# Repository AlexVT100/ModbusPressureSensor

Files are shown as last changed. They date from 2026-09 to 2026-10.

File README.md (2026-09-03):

<H1>
<picture>
    <source media="(prefers-color-scheme: dark)" srcset="images/icon_dark.svg" width="80" />
    <source media="(prefers-color-scheme: light)" srcset="images/icon.svg" width="80" />
    
</picture>
The Modbus Pressure Sensor
</H1>

## The Project's goal

The project is designed to continuously monitor coolant pressure in a residential home's heating system using Home Assistant.

## The Project's Prototype

This project is based on [Датчик давления воды для умного дома](https://www.drive2.ru/c/718805452854398890/)

## Features

* **Continuous pressure monitoring:** Tracks coolant pressure and publishes it via an integrated Modbus server.
* **Status register:** Indicates sensor failure or user-defined pressure threshold violations.
* **Integrated Telnet server:** Allows for easy remote monitoring, debugging, and configuration.
* **Custom integration for Home Assistant:** Configurable Python-based sensor integration and YAML-based alerting automation.

## Schematic

### Breadboard View

<br />Sensor Breadbord View

### Schematic Diagram

<br />
<picture>
    <source media="(prefers-color-scheme: dark)" srcset="images/schematic_dark.svg" width="600" />
    <source media="(prefers-color-scheme: light)" srcset="images/schematic_light.svg" width="600" />
    Sensor Schematic
</picture>

The [Fritzing project file](hardware/schematics/fritzing/Sensor.fzz) can be found in `schematic` folder.

## Assembly

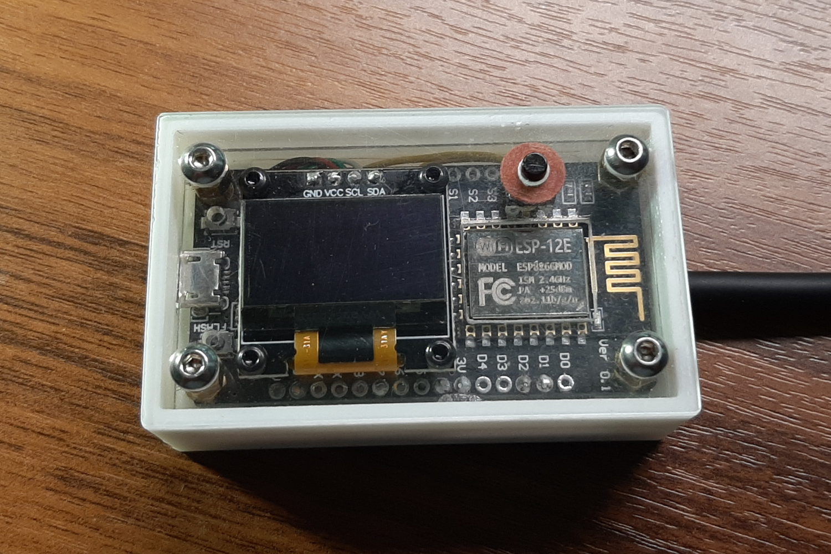
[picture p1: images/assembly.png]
The finlal assembly
<br />

<details>
  <summary>More pictures</summary>
  
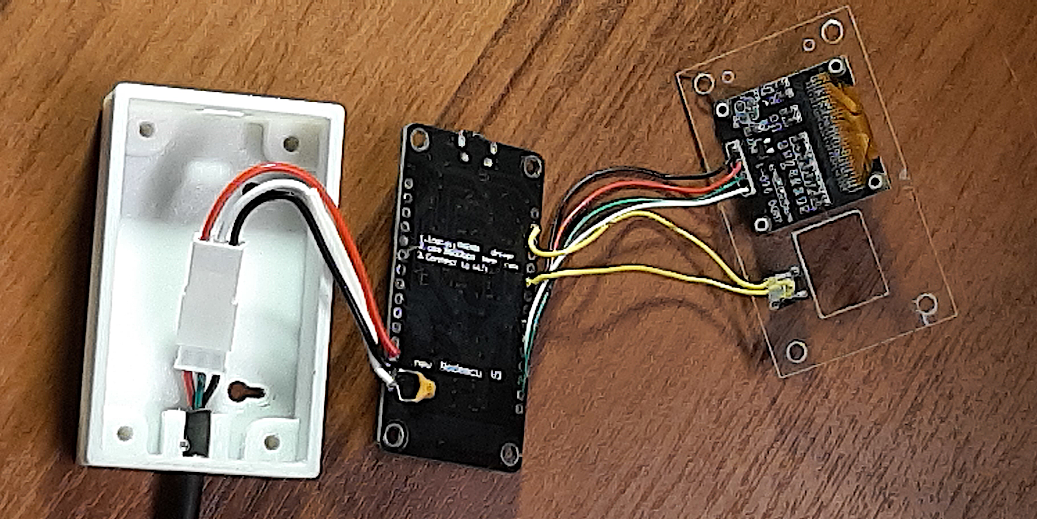
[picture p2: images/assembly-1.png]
  <br />
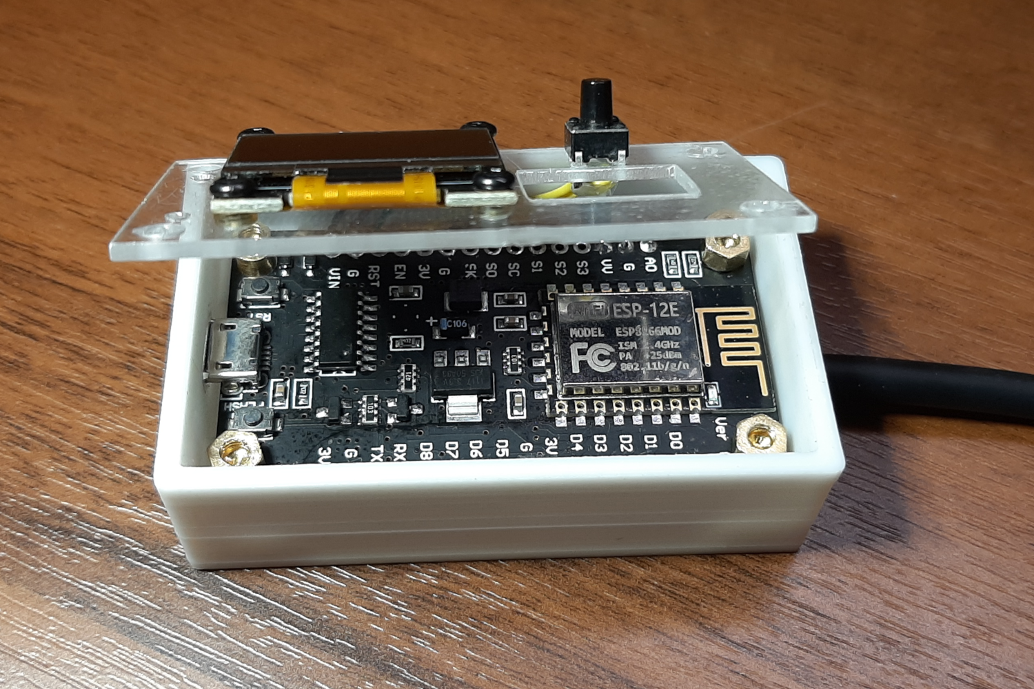
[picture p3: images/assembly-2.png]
  <br />
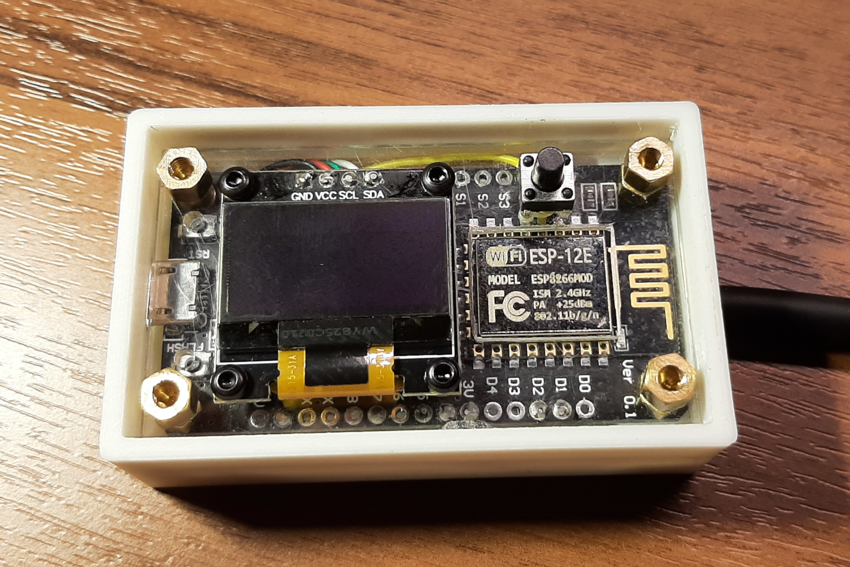
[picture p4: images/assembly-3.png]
  <br />

</details>

## Firmware

The sensor's firmware is developed in C++ using the [VSCode PlatformIO add-on](https://platformio.org/).

### Telnet output example:

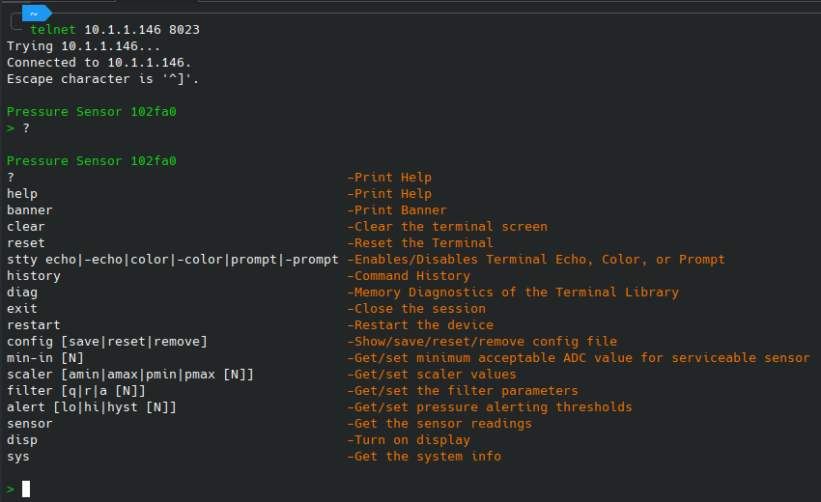
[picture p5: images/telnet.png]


### Used Arduino Libraries

* [Adafruit_SSD1306](https://github.com/adafruit/Adafruit_SSD1306) by Adafruit
* [ArduinoJson](https://github.com/bblanchon/ArduinoJson) by Benoit Blanchon
* [modbus-esp8266](https://github.com/emelianov/modbus-esp8266) by Andre Sarmento Barbosa and Alexander Emelianov
* [Terminal](https://github.com/johngavel/Terminal) by John J. Gavel
* [WiFiManager](https://github.com/tzapu/WiFiManager) by tzapu

## Home Assistant Integration

### Modbus Sensor Integration

The integration provides the Modbus Pressure Sensor device and entities to Home Assistant.

#### Installation

1. **Copy the component folder:** Copy the  `hass/custom_components/modbus_pressure_sensor` directory into your
`<hass volume>/custom_components/` directory.
2. **Restart Home Assistant:** Navigate to `Settings` ➞ `System` ➞ `⁝` (top right) ➞ `Restart Home Assistant` ➞ `Restart`.
3. **Configure the device:** Once Home Assistant restarts, navigate to `Settings` ➞ `Devices & Services` ➞ `Add Intergration` 
➞ search for `Modbus Pressure Sensor` and input your `Host`, `Port`, and `Device ID` in the configuration window.
4. **Verify connection:** Check the newly created sensor entities to confirm successful data transmission.

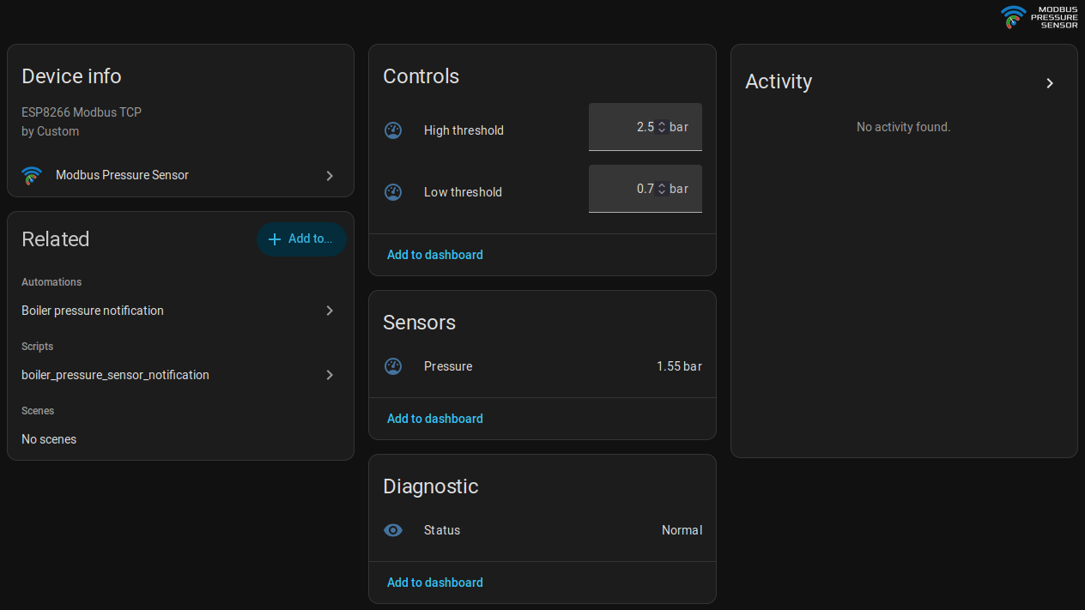
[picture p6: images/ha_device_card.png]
Sensor Breadbord View
<br />

### Alerting Automation (Optional)

This automation triggers notifications for the following events based on the status register:

* **Low pressure:** The pressure drops below the minimum threshold.
* **High pressure:** The pressure exceeds the maximum threshold.
* **Sensor failure:** The sensor reports an internal hardware error.
* **Sensor unavailable:** The sensor loses connection or stops reporting data.
* **Normal operation**: The pressure returns to the safe, standard range.

#### Installation

1. **Copy the configuration file:** Copy the `hass/packages/boiler_pressure_sensor.yaml` file into your `<hass volume>/packages/` directory.
2. **Reload configuration:** Navigate to `Settings` ➞ `⁝` (top right) ➞ `Restart Home Assistant` ➞ `Quick reload`.

## Other Useful Info

* [How to Fix Noisy Sensor Readings: Filtering Techniques for Arduino](https://zbotic.in/how-to-fix-noisy-sensor-readings-filtering-techniques-for-arduino/)

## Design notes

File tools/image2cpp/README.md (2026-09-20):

# Image to CPP Converter

Created by ChatGPT from the sources of https://github.com/javl/image2cpp

Below is a complete Python CLI tool that closely replicates the behavior of image2cpp.
It supports the same important options used in CLI ports of the project: format selection, draw mode, threshold, inversion, and bit swapping. The original tool converts images into byte arrays for microcontroller displays such as Arduino OLEDs.

This version aims to match the typical command-line usage found in community CLI conversions.

## Install dependencies

```shell
pip install pillow
```

## Example usage (same style as image2cpp CLI)

### Convert image → Arduino bitmap

```shell
python image2cpp_cli.py \
 -i logo.png \
 -o logo.c \
 -f arduino \
 -m horizontal1bit \
 -n logoBitmap
```

### Invert image

```shell
python image2cpp_cli.py -i icon.png -x
```

### Vertical byte layout

```shell
python image2cpp_cli.py -i icon.png -m vertical1bit
```

### Swap bits (useful for U8g2)

```shell
python image2cpp_cli.py -i icon.png -s
```

### Output example

```cpp
// 'logo', 128x64px
const unsigned char logo[] PROGMEM = {
  0x00, 0xFF, 0x81, 0x81, ...
};
```

## Features implemented

- CLI arguments compatible with typical image2cpp usage
- Horizontal / vertical 1-bit modes
- Arduino / plain / Adafruit GFX output
- Bit swapping
- Inversion
- Threshold control

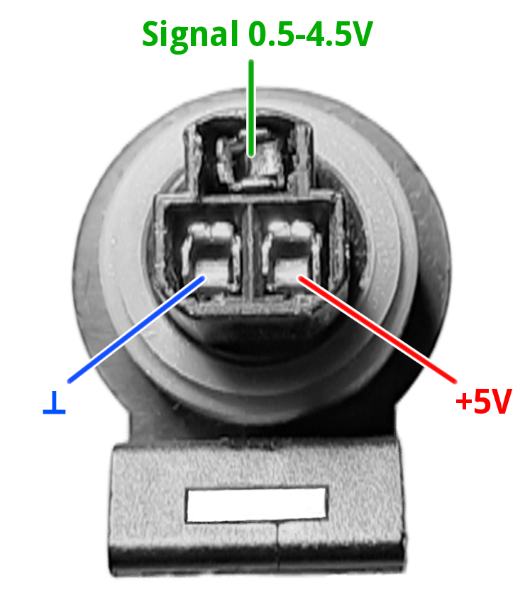
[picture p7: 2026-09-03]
images/sensor_connector.png

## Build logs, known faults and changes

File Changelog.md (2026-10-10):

# Changelog

## Firmware

### 1.2.0 (2026-10-10)
* WiFi connection logic improvement:
  * Previously, if the configured WiFi network was unavailable when the sensor started up,
    the WiFi subsystem was switched to AP mode and deleted the saved Wi-Fi credentials.
    Now, if the sensor already has saved WiFi credentials, it waits up to 5 minutes to
    connect and then restarts. It switches to AP mode only when the button is pressed
    or when no credentials are saved.
* Code reorganization:
  * The filters and the scaler have been moved to the separate files in lib/.
* Kalman filter improvements:
  * Renamed several methods.
  * Added checks for the covariance values.
  * Extended some variables to `uint64_t` to prevent potential overflow.
  * Changed `X` and `P` to use rounding instead of flooring.
* Added a unit test for Kalman filter.
* Telnet server optimization:
  * Joined commands `scale_in` and `scale_out` into single `scaler` with four parameters.
  * Removed custom GIT_REVISION and BUILD_TIME macros as they cause full rebuild on each build.
  
### 1.1.1 (2026-09-09)
* Optimized the telnet server:
	* Simplfied output of some telnet commands.
	* Removed duplicated output from the `config` command.
	* Optimized some command functions.

### 1.1.0 (2026-09-08)
* Reworked filtering:
  * The simple average filter replaced with the median filter.
  * Added the Kalman filter.
  * Added two additional Modbus input registers for debugging - the ADC readings after the median
    filter (raw) and after the Kalman filter (to be scaled).
  * The filters moved from functions.h to Filters.h/Filters.cpp.
  * scale() moved from functions.h to main.cpp.
  * Removed functions.h.
  * Removed the test scaler command from the Telnet server.

### 1.0.0 (2026-09-02)
* The first release

## Home Assistant Integration

### 1.0.0 (2026-09-02)
* The first release

## Home Assistant Automation

### 1.0.0 (2026-09-02)
* The first release

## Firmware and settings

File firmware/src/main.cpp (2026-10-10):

#include <Adafruit_SSD1306.h> // OLED display
#include <SoftwareSerial.h>   // Software UART
#include <Wire.h>

#include "ModbusHelper.h"
#include "WiFiHelper.h"

#include "Config.h"
#include "DebouncedButton.h"
#include "TelnetServer.h"
#include "TerminalLogger.h"

#include "scaler/scaler.h"
#include "filters/ema.h"
#include "filters/kalman.h"
#include "filters/median.h"

#include "States.h"
#include "bitmaps.h"

//=============================================================================
// General Settings
//=============================================================================

// SSD1306 display settings
// Character dimensions (WxH):
//      Text size 1: 5x7 (vertical spacing 1)
//      Text size 3: 15x21 (vertical spacing 2)
#define SCREEN_WIDTH   128
#define SCREEN_HEIGHT  64
#define OLED_RESET     -1 // Sharing Arduino reset pin
#define SCREEN_ADDRESS 0x3C

// Board-dependent values (discover_board.py)
#if defined(BOARD_1A86_7523) // Development board HW364A with a display and USB-C
#    define OLED_SDA     14  // D6
#    define OLED_SCL     12  // D5
#    define SERIAL_SPEED 115200
#elif defined(BOARD_0403_6001)  // No name board with MicroUSB used in the sensor assembly
#    define OLED_SDA     4      // D2
#    define OLED_SCL     5      // D1
#    define SERIAL_SPEED 115200 // 74880
#else                           // Defaults
#    define OLED_SDA     4      // D2
#    define OLED_SCL     5      // D1
#    define SERIAL_SPEED 115200
#    warning No board is connected. The image may not work as expected.
#endif

// The button pin. D5, D6 and D7 are available
#define BUTTON_PIN D7

// The size of an ADC samples buffer for oversampling
constexpr size_t MEDIAN_SIZE = 9;

//=============================================================================
// Global variables and containers
//=============================================================================

// WiFi
static constexpr unsigned WiFiConnTimeout = 300; // WiFi connection timeout, s

// Timers
static constexpr ulong SensorInterval = 500;    // Sensor polling interval, ms
static constexpr ulong DisplayInterval = 60000; // Display off timeout, ms

// millis() rollover counter for full uptime counting
ulong RolloverCount = 0;

// Display state
DisplayState DispState;

// The sensor values
SensorState Sensor;

//=============================================================================
// Global objects
//=============================================================================

// SSD-1306 display object
Adafruit_SSD1306 Display(SCREEN_WIDTH, SCREEN_HEIGHT, &Wire, OLED_RESET);

// Button press detector with debouncing
DebouncedButton Button(BUTTON_PIN);

// Wi-Fi object
WiFiHelperClass WiFiHelper("Press_Sensor_AP", Display);

// Config object
// Default settings are hardcoded in FileConfig::_setDefaults in Config.h
FileConfig Conf;

// Modbus object
ModbusHelperClass ModbusHelper;

// Kalman filter
KalmanFilterClass KalmanFilter;

// Telnet terminal and Logger
TelnetServer   Telnet(8023);
TerminalLogger Logger(Telnet);

//=============================================================================
// Forward declarations for the local functions
//=============================================================================

void      blinkLEDForever();
void      readSensor();
uint32_t *readSamples(uint8_t pin);
void      updateDisplay();
void      drawThrobber(int x, int y, int w, int h);

inline void setLEDOn() { digitalWrite(LED_BUILTIN, LOW); }
inline void setLEDOff() { digitalWrite(LED_BUILTIN, HIGH); }

// #############################################################################
//  Initialization
// #############################################################################
//
void setup() {
    Serial.begin(SERIAL_SPEED);
    while (!Serial && millis() < 3000);
    Serial.flush();

    Serial.println("\nInitialization...");

    // Switch on the built-in LED
    pinMode(LED_BUILTIN, OUTPUT);
    setLEDOn();

    // Arm the button
    pinMode(BUTTON_PIN, INPUT_PULLUP);
    Button.begin();

    // Init the display
    Wire.begin(OLED_SDA, OLED_SCL);
    if (!Display.begin(SSD1306_SWITCHCAPVCC, SCREEN_ADDRESS)) {
        // Fatal error
        blinkLEDForever();
    }
    Display.clearDisplay();
    Display.setTextSize(1);
    Display.setTextColor(SSD1306_WHITE);

    // Init the WIFI
    if (digitalRead(BUTTON_PIN) == LOW || WiFi.SSID().length() == 0) {
        // The button is pressed or no saved credentials -- enter WiFi configuration mode
        Display.clearDisplay();
        Display.setCursor(0, 0);
        Display.println(WiFi.SSID().length() == 0 ? "No WiFi credentials" : "Button pressed");
        Display.println("Starting WiFi Manager");
        Display.display();
        delay(2000);
        WiFiHelper.startWiFiManager();
    } else {
        WiFiHelper.connectToSavedWiFi(WiFiConnTimeout);
    }

    // Initialize the telnet server and te logger
    Telnet.setup();
    Logger.setup();

    // Load the configuration
    Conf.load();

    // Start the Modbus server and configure the registers
    ModbusHelper.setup();

    // Init the Kalman filter
    KalmanFilter.setCovs(Conf.kalmanQ(), Conf.kalmanR());

    // Switch off the LED
    setLEDOff();

    Serial.println("Ready");
}

// #############################################################################
//  The main loop
// #############################################################################
//
void loop() {
    static unsigned long lastMillis = millis();
    static unsigned long sensorTimer = lastMillis;
    static unsigned long displayTimer = lastMillis;

    unsigned long curMillis = millis();

    // Check if millis() rolled over back to 0
    if (curMillis < lastMillis) RolloverCount++;
    lastMillis = curMillis;

    if (curMillis - sensorTimer >= SensorInterval) {
        sensorTimer = curMillis; // Set the timer

        // Read the sensor and update the display and the Modbus registry
        readSensor();
        updateDisplay();
        ModbusHelper.pressure(Sensor.pressure >= 0 ? Sensor.pressure : 0);
        ModbusHelper.status(Sensor.status);
        ModbusHelper.adcRaw(Sensor.adcValueRaw);
        ModbusHelper.adc(Sensor.adcValue);
    }

    if (Button.wasPressed() || DispState.setOn) {
        // Switch on the display
        displayTimer = curMillis; // Set the timer
        Display.dim(false);
        DispState.isOn = true;
        DispState.setOn = false;
    }

    if (DispState.isOn && curMillis - displayTimer >= DisplayInterval) {
        // Switch off the display
        Display.dim(true);
        DispState.isOn = false;
    }

    Telnet.loop();
    ModbusHelper.loop();
    Conf.save();

    // Re-init the Kalman fiter if Q and/or R have changed
    if (KalmanFilter.covsChanged()) {
        if (KalmanFilter.setCovs(Conf.kalmanQ(), Conf.kalmanR()))
            Logger.println(INFO, F("Kalman covariance values are updated"));
        else
            Logger.println(ERROR, F("One or more Kalman filter covariance values are negative"));
    }
}

//-----------------------------------------------------------------------------
// Read the sensor
//-----------------------------------------------------------------------------
//
void readSensor() {
    //
    // Read and filter the ADC value
    //
    Sensor.adcValueRaw = median_filter(readSamples(A0), MEDIAN_SIZE);
    Sensor.adcValue    = KalmanFilter.update(Sensor.adcValueRaw);

    //
    // Calculate the pressure (mbar)
    //
    if (Sensor.adcValue > Conf.adcMinServ()) {
        Sensor.pressRaw =
            scale(Sensor.adcValue, Conf.scalerAmin(), Conf.scalerAmax(), Conf.scalerPmin(), Conf.scalerPmax());
        if (Sensor.pressRaw < 0) {
            Sensor.pressure = 0;
        } else {
            // Pressure is rounded to tens
            Sensor.pressure = ema_filter(Sensor.pressRaw, Conf.emaAlpha() * 100);
            Sensor.pressure = ((Sensor.pressure + 5) / 10) * 10;
        }

        // Set the sensor status
        if (Sensor.status == Status::LO_PRESS) {
            if (Sensor.pressure > Conf.alertLo() + Conf.alertHyst()) Sensor.status = Status::NORMAL;
        } else if (Sensor.status == Status::HI_PRESS) {
            if (Sensor.pressure + Conf.alertHyst() < Conf.alertHi()) Sensor.status = Status::NORMAL;
        } else {
            if (Sensor.pressure < Conf.alertLo())
                Sensor.status = Status::LO_PRESS;
            else if (Sensor.pressure > Conf.alertHi())
                Sensor.status = Status::HI_PRESS;
            else
                Sensor.status = Status::NORMAL;
        }
    } else {
        Sensor.pressure = 0;
        Sensor.status   = Status::FAILURE;
    }
}

//-----------------------------------------------------------------------------
// Read MEDIAN_SIZE of samples into the static buffer
//-----------------------------------------------------------------------------
//
uint32_t *readSamples(uint8_t pin) {
    static uint32_t buf[MEDIAN_SIZE];

    // Ignore the first reading in a series as it usually stands out
    // of the rest (an ADC peculiarity? an RC-filter feature?)
    analogRead(pin);

    // Collect the samples
    for (size_t i = 0; i < MEDIAN_SIZE; i++) {
        delay(2);
        buf[i] = analogRead(pin);
    }

    return buf;
}

//-----------------------------------------------------------------------------
// Update the display
//-----------------------------------------------------------------------------
//
void updateDisplay() {

    if (!DispState.isOn) return;

    Display.clearDisplay();
    Display.setCursor(0, 0);
    Display.setTextColor(SSD1306_WHITE);

    // Display.drawRect(0, 0, 128, 64, SSD1306_WHITE);

    // Print the WiFi info
    Display.setTextSize(1);
    Display.print("WiFi: ");
    Display.println(WiFiHelper.SSID());
    Display.print("  IP: ");
    Display.println(WiFiHelper.localIP());

    Display.println("");

    // Draw the icon depending on the Sensor.pressure value
    const unsigned char *bitmap;
    switch (Sensor.status) {
        case Status::NORMAL: // The Sensor.pressure is normal
            setLEDOff();
            bitmap = bitmap_none;
            break;
        case Status::LO_PRESS: // The Sensor.pressure is too low
            setLEDOn();
            bitmap = bitmap_low;
            break;
        case Status::HI_PRESS: // The Sensor.pressure is too high
            setLEDOn();
            bitmap = bitmap_high;
            break;
        default: // Just in case
            Sensor.status = Status::FAILURE;
        case Status::FAILURE: // The sensor failure
            setLEDOn();
            bitmap = bitmap_fault;
            break;
    }
    Display.drawBitmap(Display.getCursorX(), Display.getCursorY(), bitmap, BITMAP_W, BITMAP_H, SSD1306_WHITE);

    // Display the Sensor.pressure
    if (Sensor.status != Status::FAILURE) {
        Display.setTextSize(3);
        Display.setCursor(BITMAP_W + 8, Display.getCursorY());
        Display.printf("%u.%02u", Sensor.pressure / 1000, Sensor.pressure % 1000 / 10);
        // Display.setCursor(Display.getCursorX(), 38);  // Uncomment to align the next line on the bottom
        Display.setTextSize(1);
        Display.print(" bar");
    } else {
        Display.setTextSize(2);
        Display.setCursor(BITMAP_W + 8, Display.getCursorY() - 4);
        Display.println("Sensor");
        Display.setCursor(BITMAP_W + 8, Display.getCursorY() - 2);
        Display.print("failure");
    }

    // The debug info in the bottom line
    Display.setCursor(0, SCREEN_HEIGHT - 8);
    Display.setTextSize(1);
    Display.printf("M%d T%d A%04u %04d/%04d", ModbusHelper.connCount(), Telnet.isConnected(), Sensor.adcValue,
                   Conf.alertLo(), Conf.alertHi());

    // Update the throbber
    drawThrobber(122, 0, 6, 6);

    // Redraw the screen
    Display.display();
}

//-----------------------------------------------------------------------------
// Blink LED forever on fatal error. The function never returns.
//-----------------------------------------------------------------------------
//
void blinkLEDForever() {
    while (1) {
        setLEDOn();
        delay(250);
        setLEDOff();
        delay(250);
    }
}

//-----------------------------------------------------------------------------
// The throbber
//-----------------------------------------------------------------------------
//
void drawThrobber(int x, int y, int w, int h) {
    static int step = 0;

    // Draw on each call
    if (step % 2)
        Display.drawRect(x, y, w, h, SSD1306_WHITE);
    else
        Display.fillRect(x, y, w, h, SSD1306_WHITE);

    step = (step + 1) % 2; // 0 or 1 in rotation
}

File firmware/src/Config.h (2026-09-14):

#pragma once

#include <ArduinoJson.h>
#include <LittleFS.h>

class FileConfig {
  protected:
    const char *_fileName = "/config.json";
    File _file;

    class AlertConfig {
        uint16_t lo;
        uint16_t hi;
        uint16_t hyst;
    };

    struct ConfigStruct {
        uint16_t adcMinServ = 80; // Minimum acceptable ADC value for serviceable sensor

        // The linear scaler definition points
        uint16_t scalerAmin = 114;  // ADC reading corresponding to P_MIN
        uint16_t scalerAmax = 1024; // ADC reading corresponding to P_MAX
        uint16_t scalerPmin = 0;    // Minimum pressure, mbar
        uint16_t scalerPmax = 6245; // Maximum pressure, mbar

        // Filters
        float kalmanQ = 0.1;  // Kalman Q: Process noise variance
        float kalmanR = 1.0;  // Kalman R: Measurement noise variance
        float emaAlpha = 0.1; // Pressure EMA filter alpha

        // Pressure alert thresholds
        uint16_t alertLo = scalerPmin; // Low pressure
        uint16_t alertHi = scalerPmax; // High pressure
        uint16_t alertHyst = 50;       // Back to normal hysteresis
    } _config;

    const ConfigStruct _config_def = _config;
    bool _dirty = false;

  protected:
    void _setDefaults();

  public:
    FileConfig();
    bool load();
    bool save(bool force = false);
    bool reset();
    bool remove();
    String print();

    // Getters
    inline uint16_t adcMinServ() const { return _config.adcMinServ; }
    inline uint16_t scalerAmin() const { return _config.scalerAmin; }
    inline uint16_t scalerAmax() const { return _config.scalerAmax; }
    inline uint16_t scalerPmin() const { return _config.scalerPmin; }
    inline uint16_t scalerPmax() const { return _config.scalerPmax; }
    inline float kalmanQ() const { return _config.kalmanQ; }
    inline float kalmanR() const { return _config.kalmanR; }
    inline float emaAlpha() const { return _config.emaAlpha; }
    inline uint16_t alertLo() const { return _config.alertLo; };
    inline uint16_t alertHi() const { return _config.alertHi; };
    inline uint16_t alertHyst() const { return _config.alertHyst; };

    // Setters
    bool adcMinServ(uint16_t value);
    bool scalerAmin(uint16_t value);
    bool scalerAmax(uint16_t value);
    bool scalerPmin(uint16_t value);
    bool scalerPmax(uint16_t value);
    bool kalmanQ(float value);
    bool kalmanR(float value);
    bool emaAlpha(float value);
    bool alertLo(uint16_t value);
    bool alertHi(uint16_t value);
    bool alertHyst(uint8_t value);
};

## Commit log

2026-09-14 Rework filtering
2026-10-10 Refactor filters
2026-10-10 Add unit test for Kalman filter
